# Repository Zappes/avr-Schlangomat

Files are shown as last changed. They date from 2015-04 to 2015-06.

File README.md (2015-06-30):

Der Schlangomat
===============

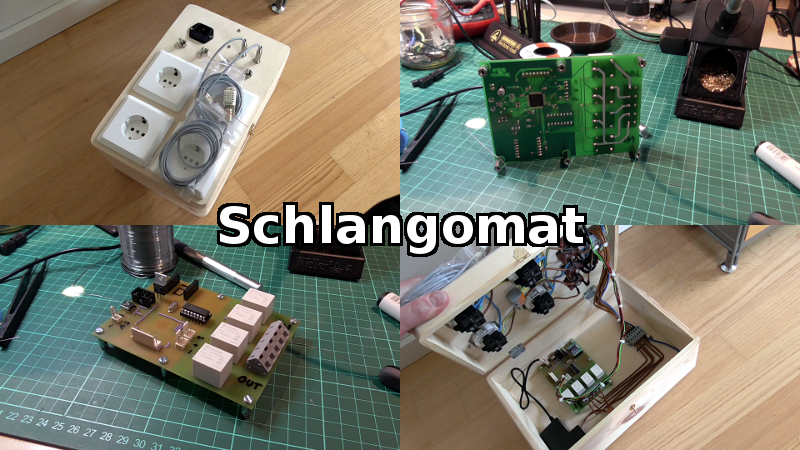
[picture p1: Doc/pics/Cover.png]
Symbolbild


Was ist das?
------------
Der Schlangomat ist eine Kiste mit etwas Elektronik, ein paar Relais und zwei kombinierten Feuchtigkeits- und Temperatursensoren.
In der Kiste sind Steckdosen verbaut, die über Relais anhand gewisser Regeln an- und ausgeschaltet werden. Zusätzlich kann der
aktuelle Zustand der Dosen und Sensoren per WLAN abgefragt werden und die verschiedenen Betriebsparameter können mit einem
seriellen Terminal per USB programmiert werden.

Gedacht ist das ganze
als "Proof of Concept" für die Klimatisierung von Terrarien mit Schlangen drin - natürlich nur als Test und auf gar keinen fickenden
Fall für den tatsächlichen Einsatz. Ich bin schließlich kein Elektriker und baue deswegen keine Geräte, die mit Netzspannung
betrieben werden.

Was steckt so drin?
-------------------
Der Mikrocontroller ist ein ATmega32U4 von Atmel, der den USB-Controller schon drin hat. Für die WLAN-Anbindung wird ein ESP8266-03-Modul
benutzt, das mit der ganz normalen AT-Firmware läuft. Die Relais sind 36.11-Relais von Finder, die von einem ULN2003A angesteuert werden.

Output per http
---------------
Wenn man per http auf die IP des Geräts zugreift, kriegt man den folgenden Output zurück:

```
{"sock":[0,0,0,0],"sens":[{"h":45.9,"t":25.9,"e":0,"c":0},{"h":46.7,"t":26.2,"e":0,"c":0}],"rule":["T1 15 18","H1 32 38","T2 21 26","H2 34 50"]}
```

- sock: Der Zustand der Steckdosen von Dose 1 bis Dose 4. Im Beispiel ist nur die 3 an.
- sens: Die aktuellen Messwerte. h steht für die relative Luftfeuchtigkeit in Prozent, t für die Temperatur in °C, e für einen Errocode und c dafür, wie fot dieser Fehler jetzt in Folge aufgetreten ist.
- rule: Die aktuellen Regeln von Dose 1 bis Dose 4. Mehr dazu weiter unten.

Das Mistding schickt wirklich nur diesen Output, keine HTTP-Header. Hintergrund ist schlicht und ergreifend ein Bug in der
Firmware des WLAN-Moduls, wegen dem es nicht möglich ist, CRLF-Sequenzen zu schicken. Wer eine Lösung dafür findet, möge bitte
einen Pull-Request schicken ...

Intern werden die Sensoren nur etwa alle 5 Sekunden abgefragt. Wenn bei der Abfrage ein Fehler auftritt, steht dieser im Errorcode des Ergebnisses,
als Temperatur und Feuchtigkeit werden dann jeweils 0.0 gemeldet. Wenn der Fehler bei mehreren Abfragen in Forlge auftritt, steht in c die Anzahl
dieser Fehlversuche oder 255, wenn es schon mehr als 254 mal passiert ist. Was die genauen Fehlercodes bedeuten, kann man sich in lib/am2302.c
raussuchen, bei Code 4 kann man aber meistens davon ausgehen, dass der Sensor schlicht nicht eingesteckt ist. Oder total im Arsch.

USB-Kommandos
-------------

Wenn man ein USB-Kabel in das Gerät pöppelt, kann man sich mit einem seriellen Terminal verbinden. Als Verbindungsparameter sind 9600 8N1 zu verwenden, lokales Echo kann man sich schenken. Linuxer können das
beispielsweise so angehen:

```
minicom --device /dev/ttyACM0 -b 9600
```

Windowser verwenden vermutlich Putty oder Teraterm oder sowas.

In der seriellen Konsole hat man nun die folgenden Befehle:

| Befehl | Parameter | Beschreibung
|---|---|---
| espsetup | | Initialisiert den WLAN-Chip.
| esp | esp-kommando | Führt ein ESP-Kommando aus - siehe weiter unten.
| setrule | dose [regel] | Setzt eine Regel für eine Dose, z.b. mit "setrule 1 T1 23 27". Ohne Regel wird die Regelausführung für die Dose deaktiviert
| getrule | [dose] | Gibt eine Regel aus. Ohne Parameter werden alle Regeln ausgegeben.
| on | [dose] | Schaltet eine Dose an. Wird die Dose nicht angegeben, werden alle Dosen aktiviert.
| off | [dose] | Schaltet eine Dose ab. Wird die Dose nicht angegeben, werden alle Dosen deaktiviert.
| state | | Gibt den aktuellen Zustand der Dosen aus.
| sens | | Gibt den aktuellen Zustand der Sensoren aus.
| setinterval | Sekunden | Setzt das Intervall, in dem die Sensoren abgefragt und die Regeln ausgeführt werden.
| getinterval | Sekunden | Zeigt das Intervall, in dem die Sensoren abgefragt und die Regeln ausgeführt werden, an.

Die Regelsyntax
---------------

Die Regeln beziehen sich immer auf eine Steckdose und können die jeweilige Dose abhängig von der Temperatur oder Luftfeuchtigkeit eines der beiden Sensoren messen. Das Format beim Setzen der Regel ist wie folgt:

```
setrule [Dose] [T|H][Sensor] [Minimum] [Maximum]
```

Angenommen, an Dose 3 hängt eine Heizung für das Terrarium, in dem Sensor 2 angebracht ist. Nun soll eine Regel die Temperatur zwischen 25 und 28 °C halten. Der entsprechende Befehl sieht wie folgt aus:

```
setrule 3 T2 25 28
```

Dabei ist zu beachten, dass die Firmware derzeit davon ausgeht, dass die Geräte an den Dosen die Messwerte ERHÖHEN, d.h. wie eine Heizung oder ein Befeuchter funktionieren. Würde man Kühlungen oder Entfeuchter anschließen wollen, wäre eine Firmware nötig, bei der man angeben kann, welche Wirkung die Geräte haben.

Die ESP-Befehle
---------------

Mit dem Befehl "esp" können Befehle an den ESP-Chip durchgereicht werden. Dabei ist zu beachten, dass das nur für die "normalen" Befehle funktioniert, die am Ende "OK" oder "ERR" ausgeben. Kompliziertes Zeug wie CIPSEND funktioniert so nicht, und die Ausgabe beim Reset ist zumindest eigentümlich.

Typischerweise braucht man die ESP-Befehle sowieso nur, um sich mit einem WLAN-AP zu verbinden. Dafür zeigt man sich erst mal mit ESP AT+CWLAP die Namen der APs an, dann verbindet man sich mittels ESP AT+CWJAP="SSID","PASS".

Die Frontplatte
---------------

Die Beschaltung der Frontplatte ist wie folgt:

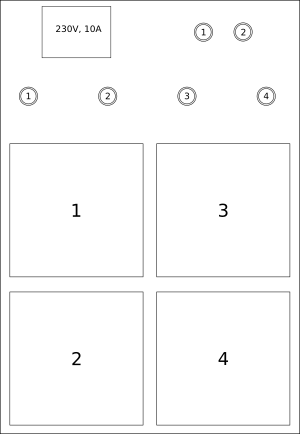
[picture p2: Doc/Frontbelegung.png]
Frontplattenbeschaltung


Gibt es Videos?
-----------------------
[Natürlich gibt es eine Youtube-Playlist.](https://www.youtube.com/playlist?list=PLFFlJlvZ--PkRfQQ3qQJbDEAugWxiXpbW)

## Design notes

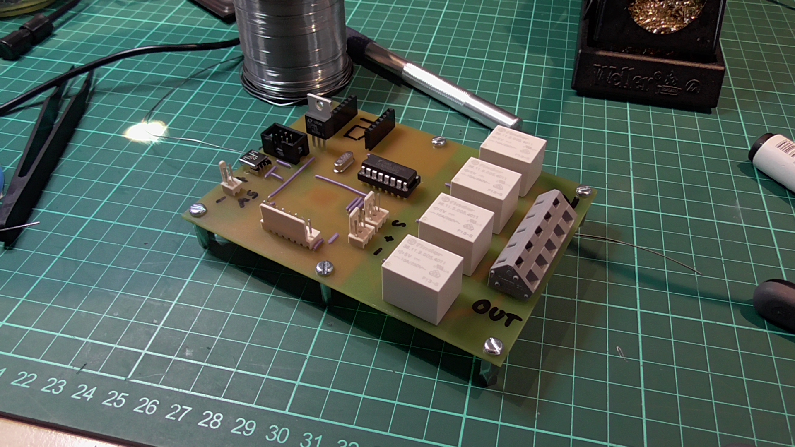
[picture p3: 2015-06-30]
Doc/pics/Platine oben.JPG

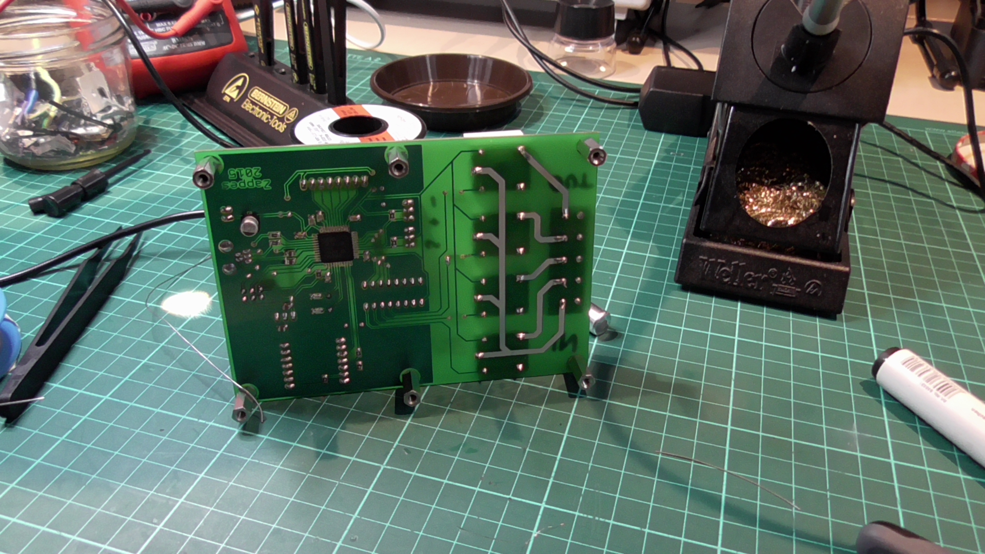
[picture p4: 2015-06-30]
Doc/pics/Platine unten.JPG

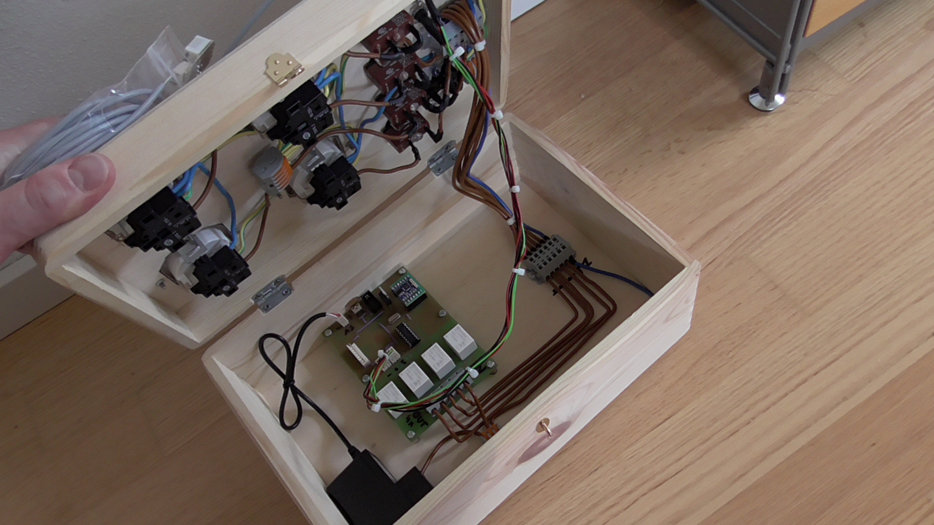
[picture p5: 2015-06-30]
Doc/pics/Box offen.JPG

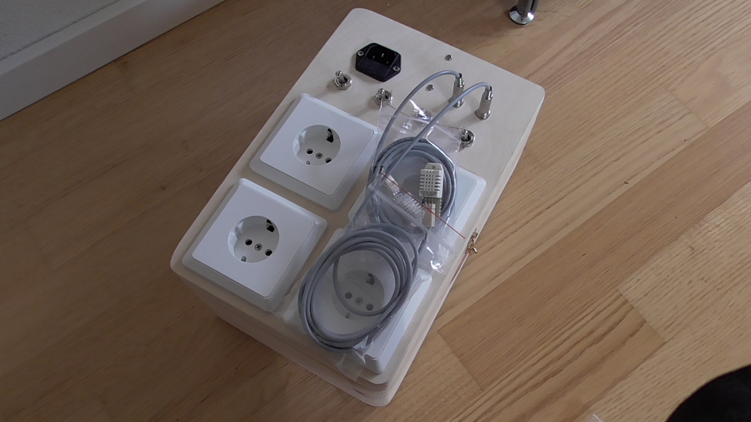
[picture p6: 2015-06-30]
Doc/pics/Box geschlossen.JPG

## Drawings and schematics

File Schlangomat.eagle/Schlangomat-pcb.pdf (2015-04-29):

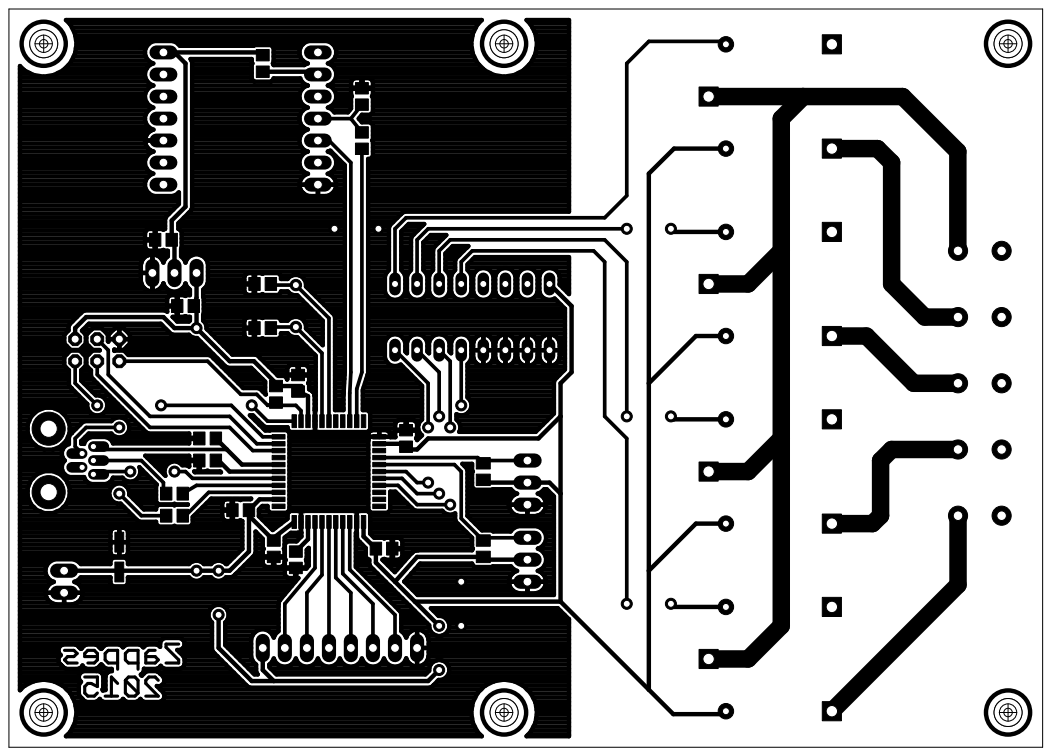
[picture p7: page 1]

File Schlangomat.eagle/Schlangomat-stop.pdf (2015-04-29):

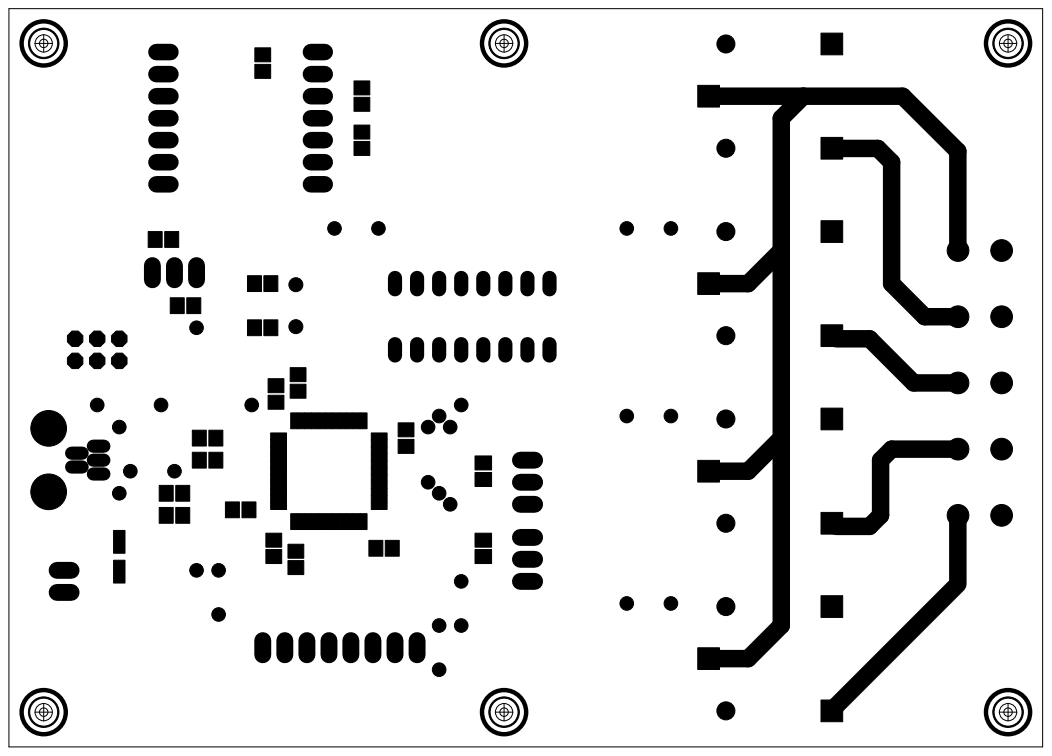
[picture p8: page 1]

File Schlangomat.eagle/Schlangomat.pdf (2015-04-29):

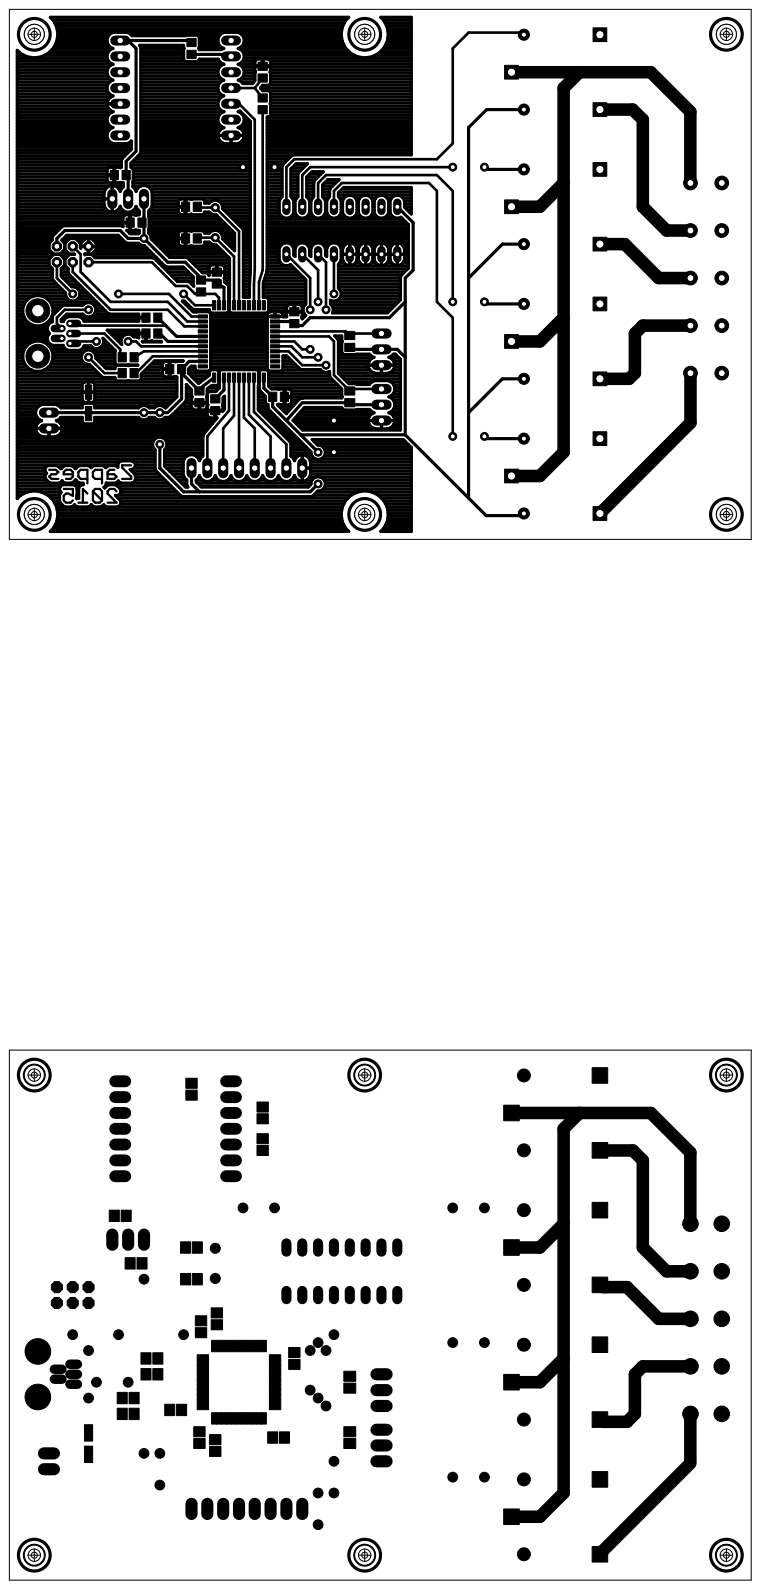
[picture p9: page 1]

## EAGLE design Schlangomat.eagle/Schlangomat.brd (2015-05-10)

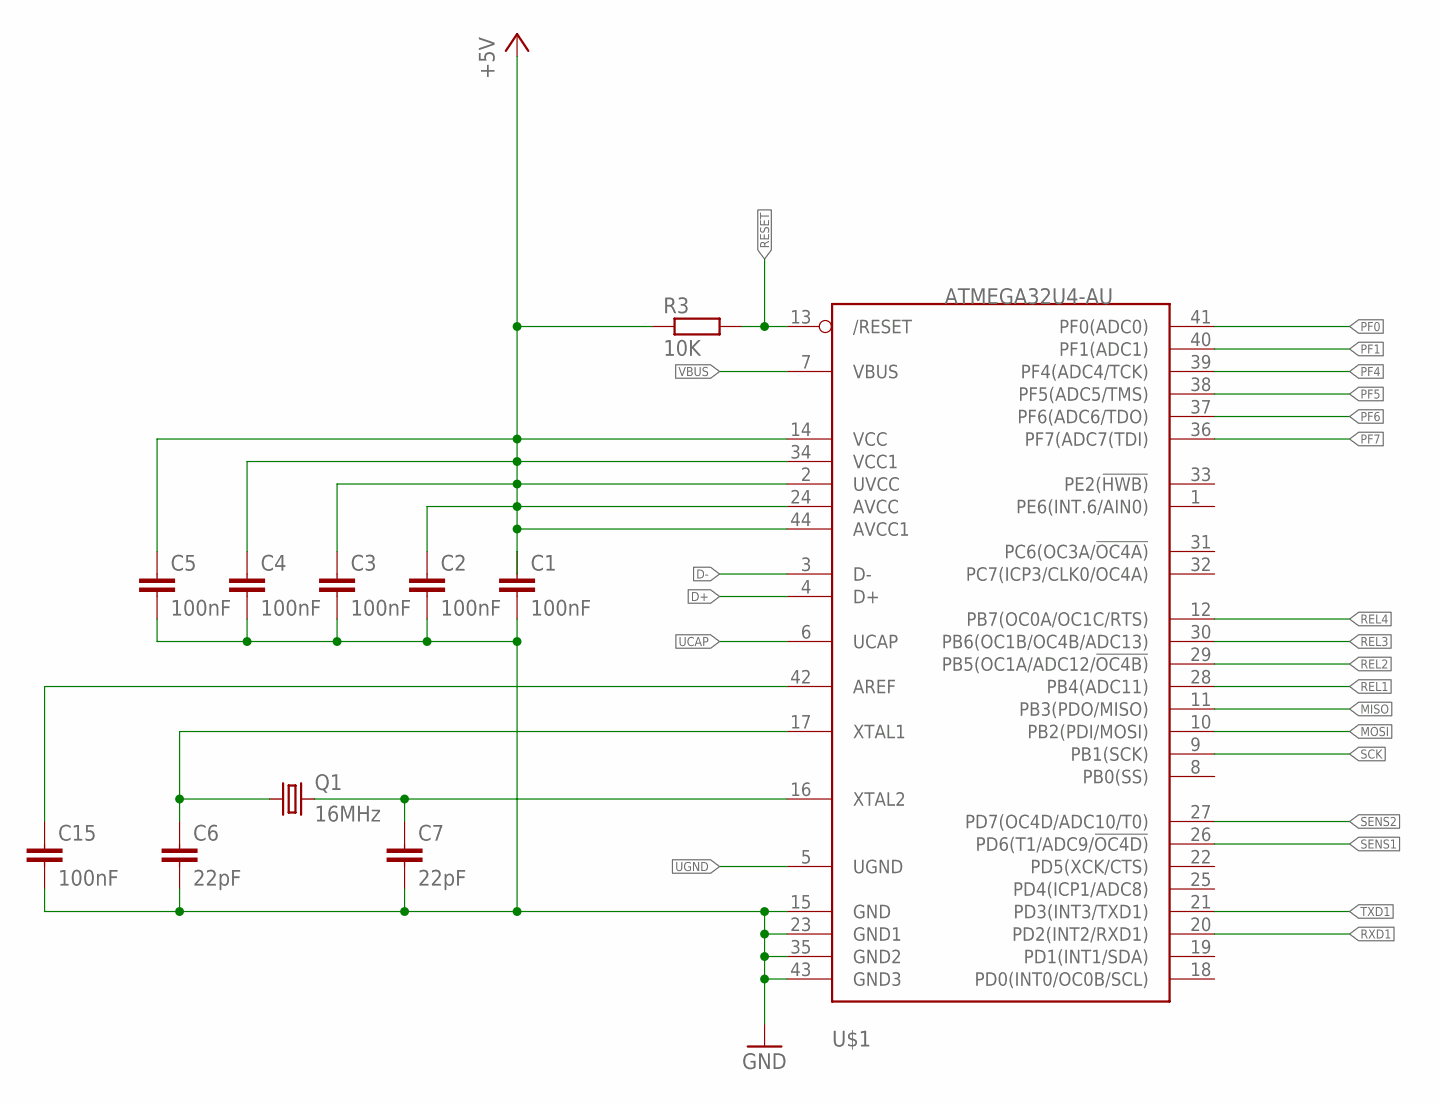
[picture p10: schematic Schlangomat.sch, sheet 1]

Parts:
C1, C2, C3, C4, C5, C15: 100nF; C0805
C6, C7: 22pF; C0805
Q1: 16MHz; HC49/S
R3: 10K; R0805
U$1: ATMEGA32U4-AU; TQFP44

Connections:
+5V: C1.1, C2.1, C3.1, C4.1, C5.1, R3.1, U$1.2 (UVCC), U$1.14 (VCC), U$1.24 (AVCC), U$1.34 (VCC1), U$1.44 (AVCC1); also elsewhere on the board
D+: U$1.4 (D+); also elsewhere on the board
D-: U$1.3 (D-); also elsewhere on the board
GND: C1.2, C2.2, C3.2, C4.2, C5.2, C6.2, C7.2, C15.2, U$1.15 (GND), U$1.23 (GND1), U$1.35 (GND2), U$1.43 (GND3); also elsewhere on the board
MISO: U$1.11 (PB3(PDO/MISO)); also elsewhere on the board
MOSI: U$1.10 (PB2(PDI/MOSI)); also elsewhere on the board
unnamed: C6.1, Q1.1, U$1.17 (XTAL1)
unnamed: C7.1, Q1.2, U$1.16 (XTAL2)
unnamed: C15.1, U$1.42 (AREF)
PF0: U$1.41 (PF0(ADC0)); also elsewhere on the board
PF1: U$1.40 (PF1(ADC1)); also elsewhere on the board
PF4: U$1.39 (PF4(ADC4/TCK)); also elsewhere on the board
PF5: U$1.38 (PF5(ADC5/TMS)); also elsewhere on the board
PF6: U$1.37 (PF6(ADC6/TDO)); also elsewhere on the board
PF7: U$1.36 (PF7(ADC7(TDI)); also elsewhere on the board
REL1: U$1.28 (PB4(ADC11)); also elsewhere on the board
REL2: U$1.29 (PB5(OC1A/ADC12/!OC4B)); also elsewhere on the board
REL3: U$1.30 (PB6(OC1B/OC4B/ADC13)); also elsewhere on the board
REL4: U$1.12 (PB7(OC0A/OC1C/RTS)); also elsewhere on the board
RESET: R3.2, U$1.13 (/RESET); also elsewhere on the board
RXD1: U$1.20 (PD2(INT2/RXD1)); also elsewhere on the board
SCK: U$1.9 (PB1(SCK)); also elsewhere on the board
SENS1: U$1.26 (PD6(T1/ADC9/!OC4D)); also elsewhere on the board
SENS2: U$1.27 (PD7(OC4D/ADC10/T0)); also elsewhere on the board
TXD1: U$1.21 (PD3(INT3/TXD1)); also elsewhere on the board
UCAP: U$1.6 (UCAP); also elsewhere on the board
UGND: U$1.5 (UGND); also elsewhere on the board
VBUS: U$1.7 (VBUS); also elsewhere on the board

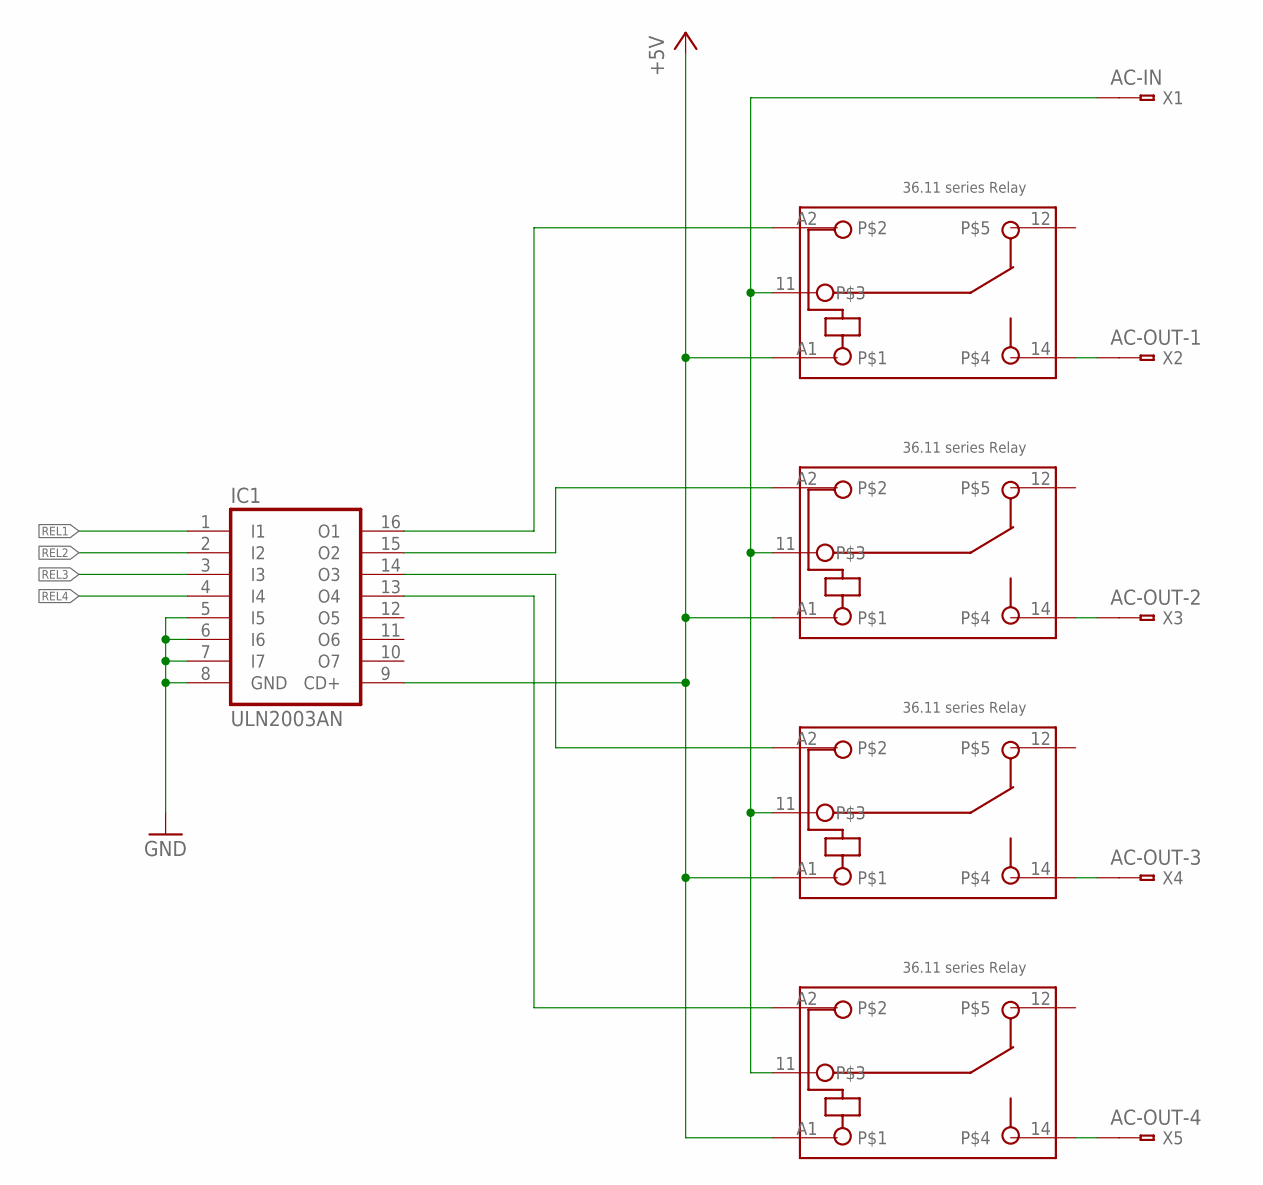
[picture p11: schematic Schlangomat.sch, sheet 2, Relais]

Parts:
IC1: ULN2003AN; DIL16
K1, K2, K3, K4: 36.11
X1: AC-IN; 236-5XX
X2: AC-OUT-1; 236-5XX
X3: AC-OUT-2; 236-5XX
X4: AC-OUT-3; 236-5XX
X5: AC-OUT-4; 236-5XX

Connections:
+5V: IC1.9 (CD+), K1.A1, K2.A1, K3.A1, K4.A1; also elsewhere on the board
AC_IN: K1.11, K2.11, K3.11, K4.11, X1.1@2 (B1)
GND: IC1.5 (I5), IC1.6 (I6), IC1.7 (I7), IC1.8 (GND); also elsewhere on the board
unnamed: IC1.16 (O1), K1.A2
unnamed: IC1.15 (O2), K2.A2
unnamed: IC1.14 (O3), K3.A2
unnamed: IC1.13 (O4), K4.A2
unnamed: K1.14, X2.1@2 (B1)
unnamed: K2.14, X3.1@2 (B1)
unnamed: K3.14, X4.1@2 (B1)
unnamed: K4.14, X5.1@2 (B1)
REL1: IC1.1 (I1); also elsewhere on the board
REL2: IC1.2 (I2); also elsewhere on the board
REL3: IC1.3 (I3); also elsewhere on the board
REL4: IC1.4 (I4); also elsewhere on the board

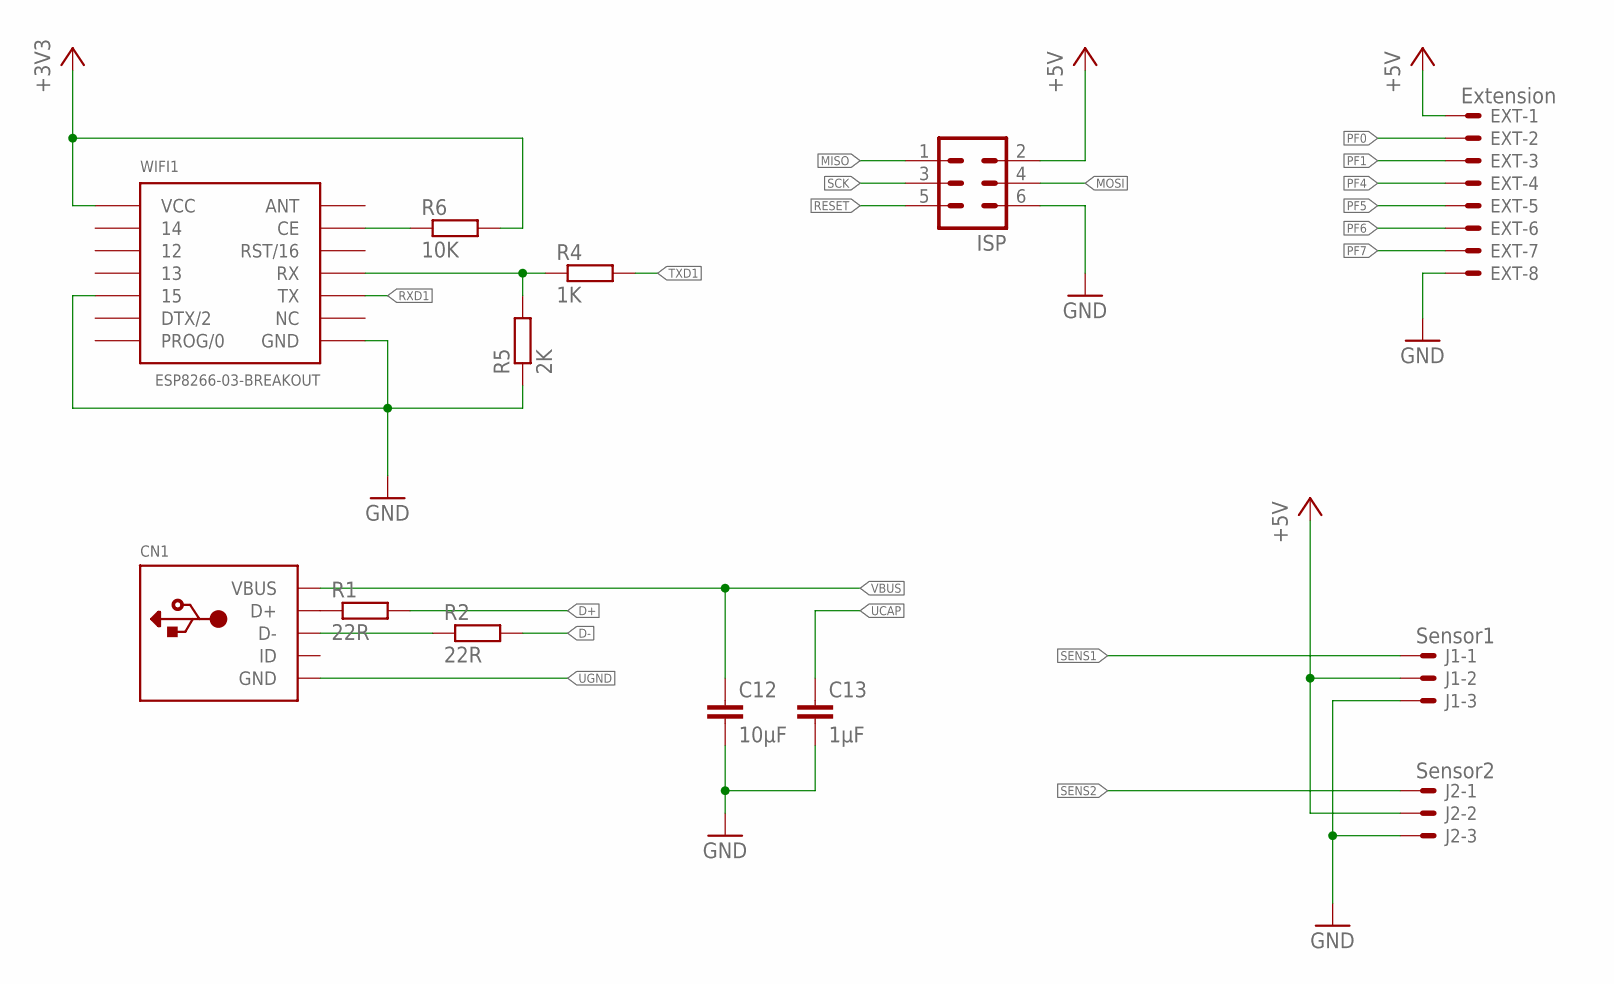
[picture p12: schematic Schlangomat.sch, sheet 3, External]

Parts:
C12: 10µF; C0805
C13: 1µF; C0805
CN1: USBMOLEX; USB-MINIB-THM-MOLEX
EXT: Extension; 6410-08
ISP: ML6
J1: Sensor1; 6410-03
J2: Sensor2; 6410-03
R1, R2: 22R; R0805
R4: 1K; R0805
R5: 2K; R0805
R6: 10K; R0805
WIFI1: ESP8266-03-BREAKOUT; ESP-03-BREAKOUT

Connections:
+3V3: R6.2, WIFI1.VCC; also elsewhere on the board
+5V: EXT.1, ISP.2, J1.2, J2.2; also elsewhere on the board
D+: R1.2; also elsewhere on the board
D-: R2.2; also elsewhere on the board
GND: C12.2, C13.2, EXT.8, ISP.6, J1.3, J2.3, R5.1, WIFI1.15, WIFI1.GND; also elsewhere on the board
MISO: ISP.1; also elsewhere on the board
MOSI: ISP.4; also elsewhere on the board
unnamed: CN1.D+, R1.1
unnamed: CN1.D-, R2.1
unnamed: R6.1, WIFI1.CE
PF0: EXT.2; also elsewhere on the board
PF1: EXT.3; also elsewhere on the board
PF4: EXT.4; also elsewhere on the board
PF5: EXT.5; also elsewhere on the board
PF6: EXT.6; also elsewhere on the board
PF7: EXT.7; also elsewhere on the board
RESET: ISP.5; also elsewhere on the board
RXD1: WIFI1.TX; also elsewhere on the board
SCK: ISP.3; also elsewhere on the board
SENS1: J1.1; also elsewhere on the board
SENS2: J2.1; also elsewhere on the board
TXD1: R4.1, R4.2, R5.2, WIFI1.RX; also elsewhere on the board
UCAP: C13.1; also elsewhere on the board
UGND: CN1.GND; also elsewhere on the board
VBUS: C12.1, CN1.VBUS; also elsewhere on the board

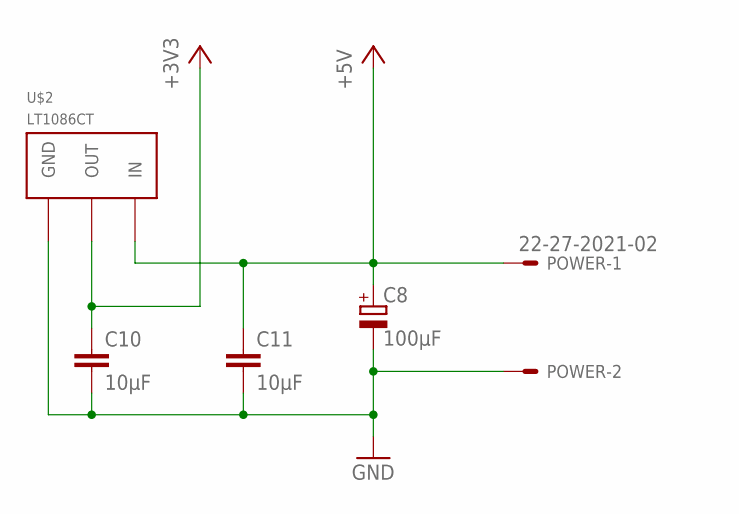
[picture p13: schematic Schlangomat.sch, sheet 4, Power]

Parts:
C8: 100µF; UD-5X5,8_NICHICON
C10, C11: 10µF; C0805
POWER: 22-27-2021-02; 6410-02
U$2: LT1086CT; TO220V

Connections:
+3V3: C10.1, U$2.2 (OUT); also elsewhere on the board
+5V: C8.+, C11.1, POWER.1, U$2.3 (IN); also elsewhere on the board
GND: C8.-, C10.2, C11.2, POWER.2, U$2.1 (GND); also elsewhere on the board

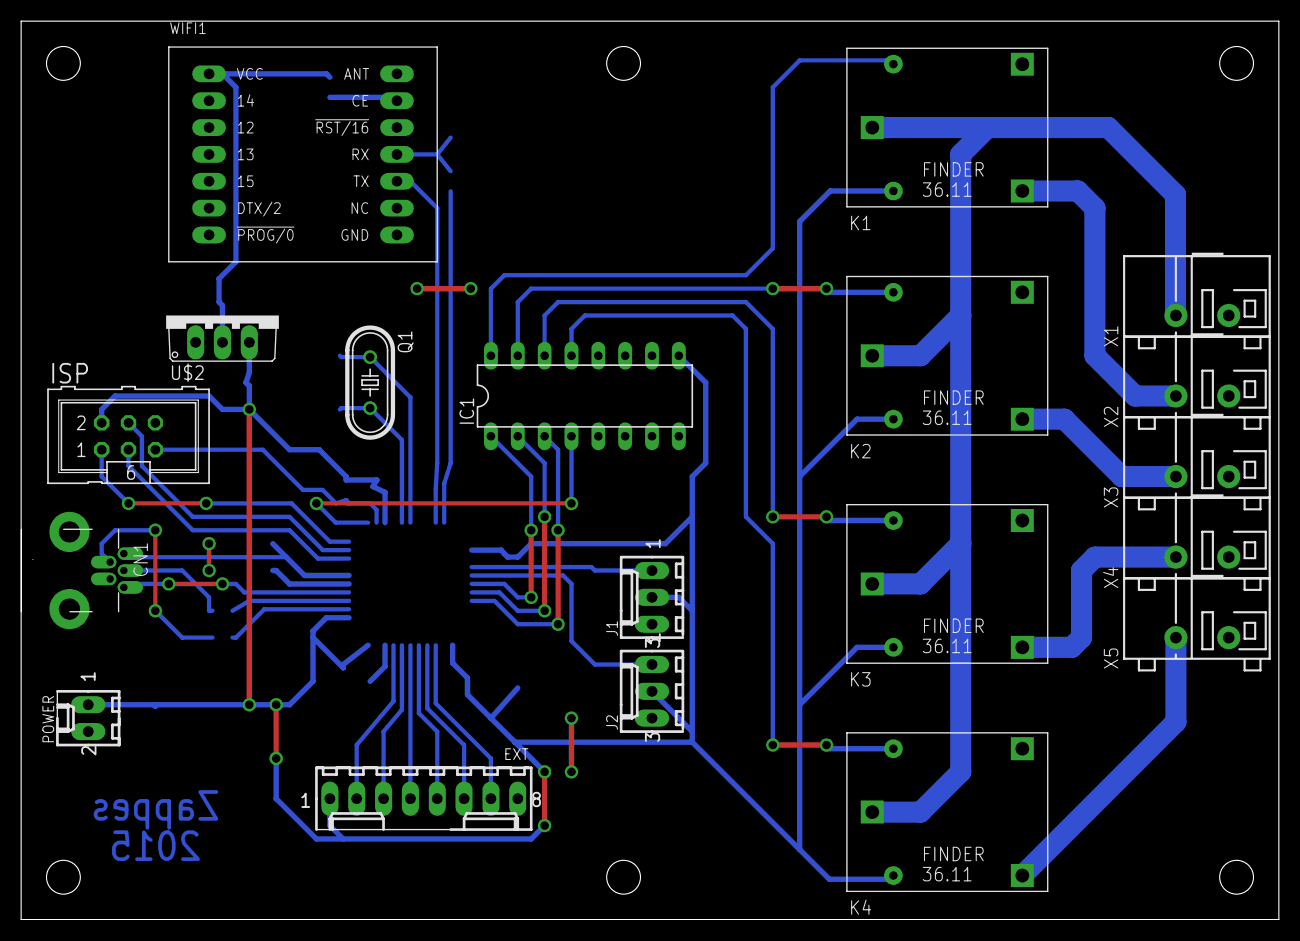
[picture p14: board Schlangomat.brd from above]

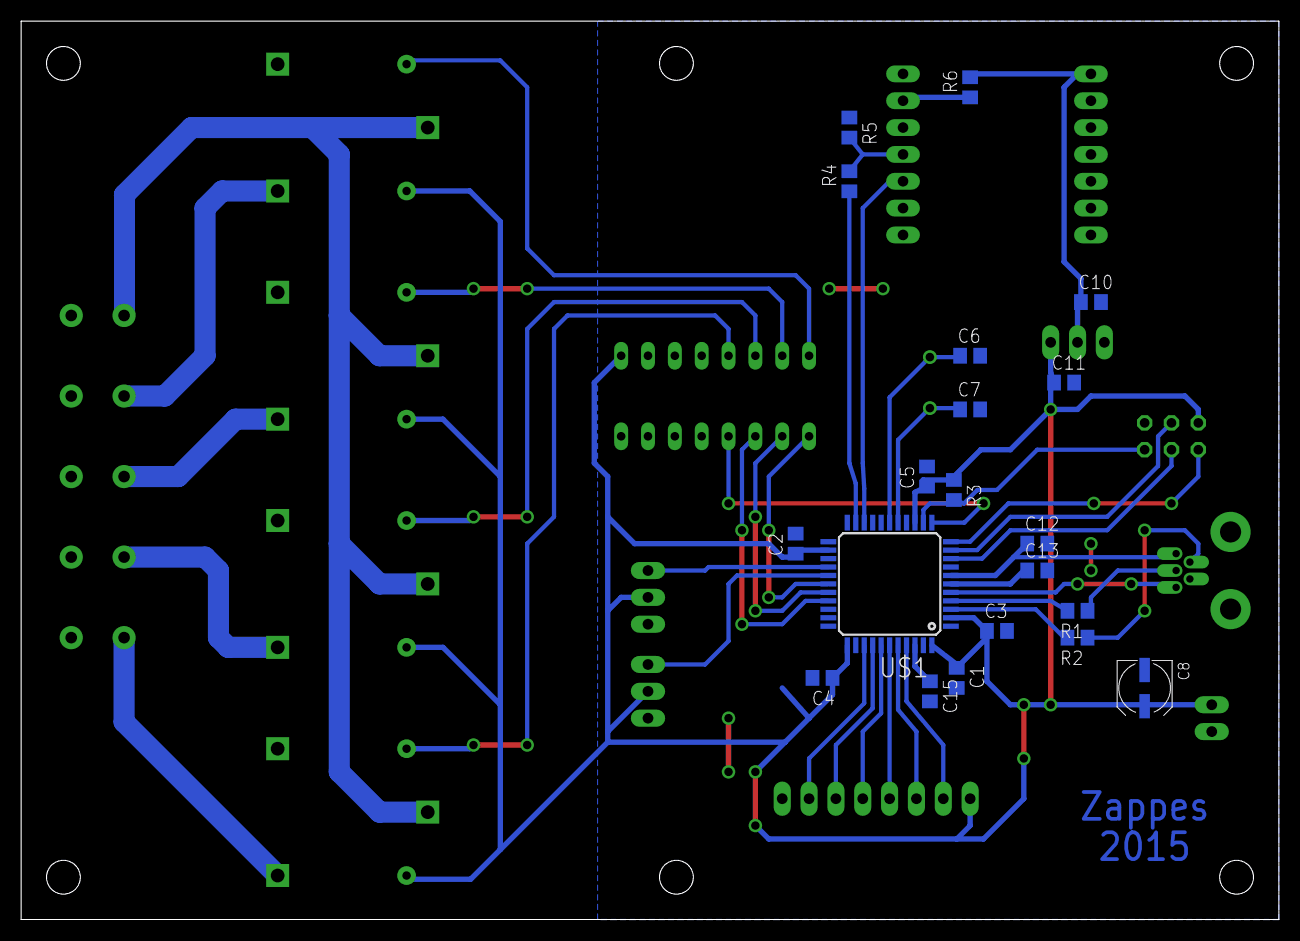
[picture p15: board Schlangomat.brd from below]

Board: 2 copper layers, 119.0 x 85.0 mm, 39 parts (20 on the bottom side), 41 nets.

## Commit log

2015-04-19 Lib für den Sensor hinzugefügt
2015-04-19 Sensor-Support eingebaut
    [Schlangomat.sch]
2015-04-29 Board gelayoutet
    [Schlangomat.brd, Schlangomat.sch]
2015-05-03 Relaissteuerung und Parser in eigene Files verlagert, allgemeinen Verbesserungen.
    [Schlangomat.brd]
2015-05-10 PullUp-FuckUp gefixt, Fehlerbeseitigt
    [Schlangomat.brd, Schlangomat.sch]
2015-05-24 Timerbasierte Abfrage der Sensoren eingebaut
2015-05-24 Timerbasierte Regelausführung
2015-05-26 Regelsyntax geändert, Ausführung und Hysterese implementiert
2015-05-31 Parseroptinmierungen und neues Regelformat
2015-06-07 Lesen von USB und ESP erheblich vereinfacht, verwendung eines ESP-Handlers für die Reaktion auf HTTP-Requests vorbereitet.
2015-06-13 Code für die Ausführung von ESP-Kommandos überarbeitet.
2015-06-22 Webserver primtiiv implementiert - auf jeden Request kommt ein JSON-String mit den Sensorwerten und Relaiszuständen zurück.
2015-06-23 Fixes am Netzwerkcode und Persistierung der Regeln im EEPROM
2015-06-23 Optimierungen bei Makefile und Persistierung
2015-06-30 Kleinkram im Zuge der Beta-Auslieferung
2015-06-30 Bild in die README eingebaut
